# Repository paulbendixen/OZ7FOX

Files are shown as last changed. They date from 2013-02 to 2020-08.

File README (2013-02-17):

This is a project to make an open source / open hardware foxhunt transmitter

All code in this project is released under Beerware license, you may use it 
any way you want. If you like it we would appreciate if you bougth us a beer 
should we meet.

The project is designed to run on an ATMega16 or ATMega32, the hardware should
be available shortly.

Best regards and 73

	Paul M. Bendixen,	OZ6PMB
	Morten E. Bruhn,	OZ1MB

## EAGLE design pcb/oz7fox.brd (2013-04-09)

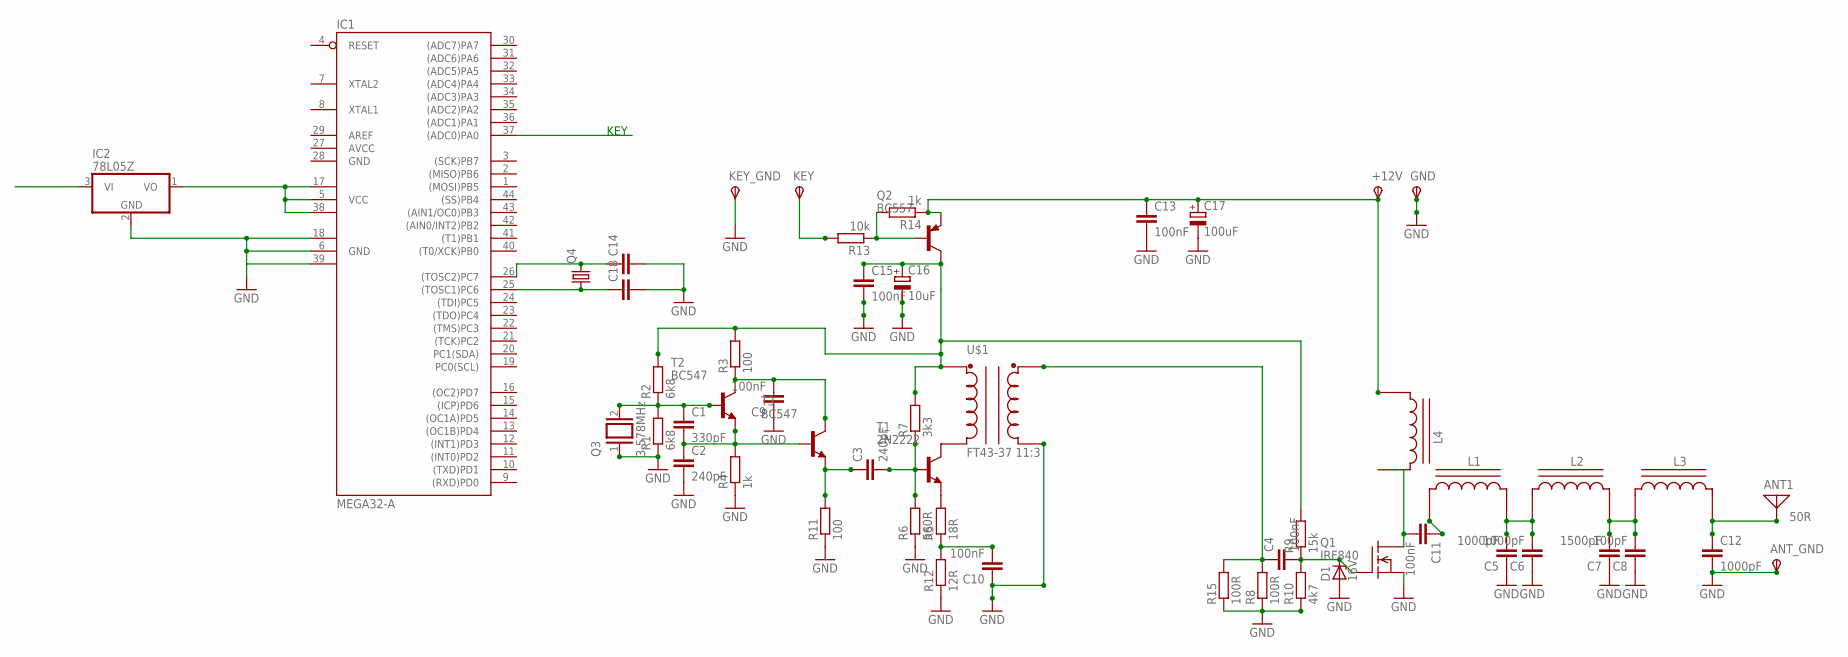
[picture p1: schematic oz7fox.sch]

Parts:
+12V: TPSPAD1-20; P1-20
ANT1: 50R; PAD-01
ANT_GND: TPSPAD1-20; P1-20
C1: 330pF; C150-054X183
C2, C3: 240pF; C150-054X183
C4, C11: 100nF; C150-054X183
C5, C6, C12: 1000pF; C150-054X183
C7: 1500pF; C150-054X183
C8: 100pF; C150-054X183
C9, C10, C13, C15: 100nF; C050-025X075
C14, C18: C5/2.5; C5B2.5
C16: 10uF; E5-13
C17: 100uF; E5-13
D1: 16V; ZDIO12.5
GND: TPSPAD1-20; P1-20
IC1: MEGA32-A; TQFP44
IC2: 78L05Z; TO92
KEY: TPSPAD1-20; P1-20
KEY_GND: TPSPAD1-20; P1-20
L1, L2, L3: T37_INDUCTOR
L4: T37-2 16t; T37_INDUCTOR
Q1: IRF840; TO220
Q2: BC557; TO92
Q3: 3,578MHz; Q
Q4: CRYSTALTC26V; TC26V
R1: 6k8; 0207/12
R2: 6k8; 0207/10
R3, R11: 100; 0207/12
R4, R14: 1k; 0207/12
R5: 18R; 0207/12
R6: 560R; 0207/12
R7: 3k3; 0207/12
R8, R15: 100R; 0207/12
R9: 15k; 0207/12
R10: 4k7; 0207/12
R12: 12R; 0207/12
R13: 10k; 0207/12
T1: 2N2222; TO18
T2, T3: BC547; TO92
U$1: FT43-37 11:3; T37_TRANSFORMER

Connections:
12V: +12V.TP, C13.1, C17.+, IC2.3 (VI), L4.CB, Q2.1 (E), R14.1
AVCC: IC1.27 (AVCC)
GND: ANT_GND.TP, C2.2, C5.1, C6.1, C7.1, C8.1, C9.1, C10.1, C12.2, C13.2, C14.2, C15.2, C16.-, C17.-, C18.2, D1.A, GND.TP, IC1.6 (GND), IC1.18 (GND1), IC1.28 (GND), IC1.39 (GND2), IC2.2 (GND), KEY_GND.TP, Q1.3 (S), Q3.1, R1.1, R4.1, R6.1, R8.1, R10.1, R11.1, R12.1, R15.1, U$1.C2A
KEY: IC1.37 ((ADC0)PA0), KEY.TP, R13.2
unnamed: C1.2, C2.1, R4.2, T2.1 (E), T3.2 (B)
unnamed: C11.1, L1.CB
unnamed: C1.1, Q3.2, R1.2, R2.1, T2.2 (B)
unnamed: C9.2, R3.1, T2.3 (C), T3.3 (C)
unnamed: C15.1, C16.+, Q2.3 (C), R2.2, R3.2, R7.2, R9.2, U$1.C1B
unnamed: C3.1, R11.2, T3.1 (E)
unnamed: C11.2, L4.CA, Q1.2 (D)
unnamed: C3.2, R6.2, R7.1, T1.2 (B)
unnamed: R5.2, T1.1 (E)
unnamed: C10.2, R5.1, R12.2
unnamed: T1.3 (C), U$1.C1A
unnamed: C5.2, C6.2, L1.CA, L2.CB
unnamed: IC1.5 (VCC), IC1.17 (VCC1), IC1.38 (VCC2), IC2.1 (VO)
unnamed: C7.2, C8.2, L2.CA, L3.CB
unnamed: C18.1, IC1.25 ((TOSC1)PC6), Q4.1
unnamed: ANT1.1, C12.1, L3.CA
unnamed: C4.1, R8.2, R15.2, U$1.C2B
unnamed: C4.2, D1.C, Q1.1 (G), R9.1, R10.2
unnamed: C14.1, IC1.26 ((TOSC2)PC7), Q4.2
unnamed: Q2.2 (B), R13.1, R14.2

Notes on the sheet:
KEY

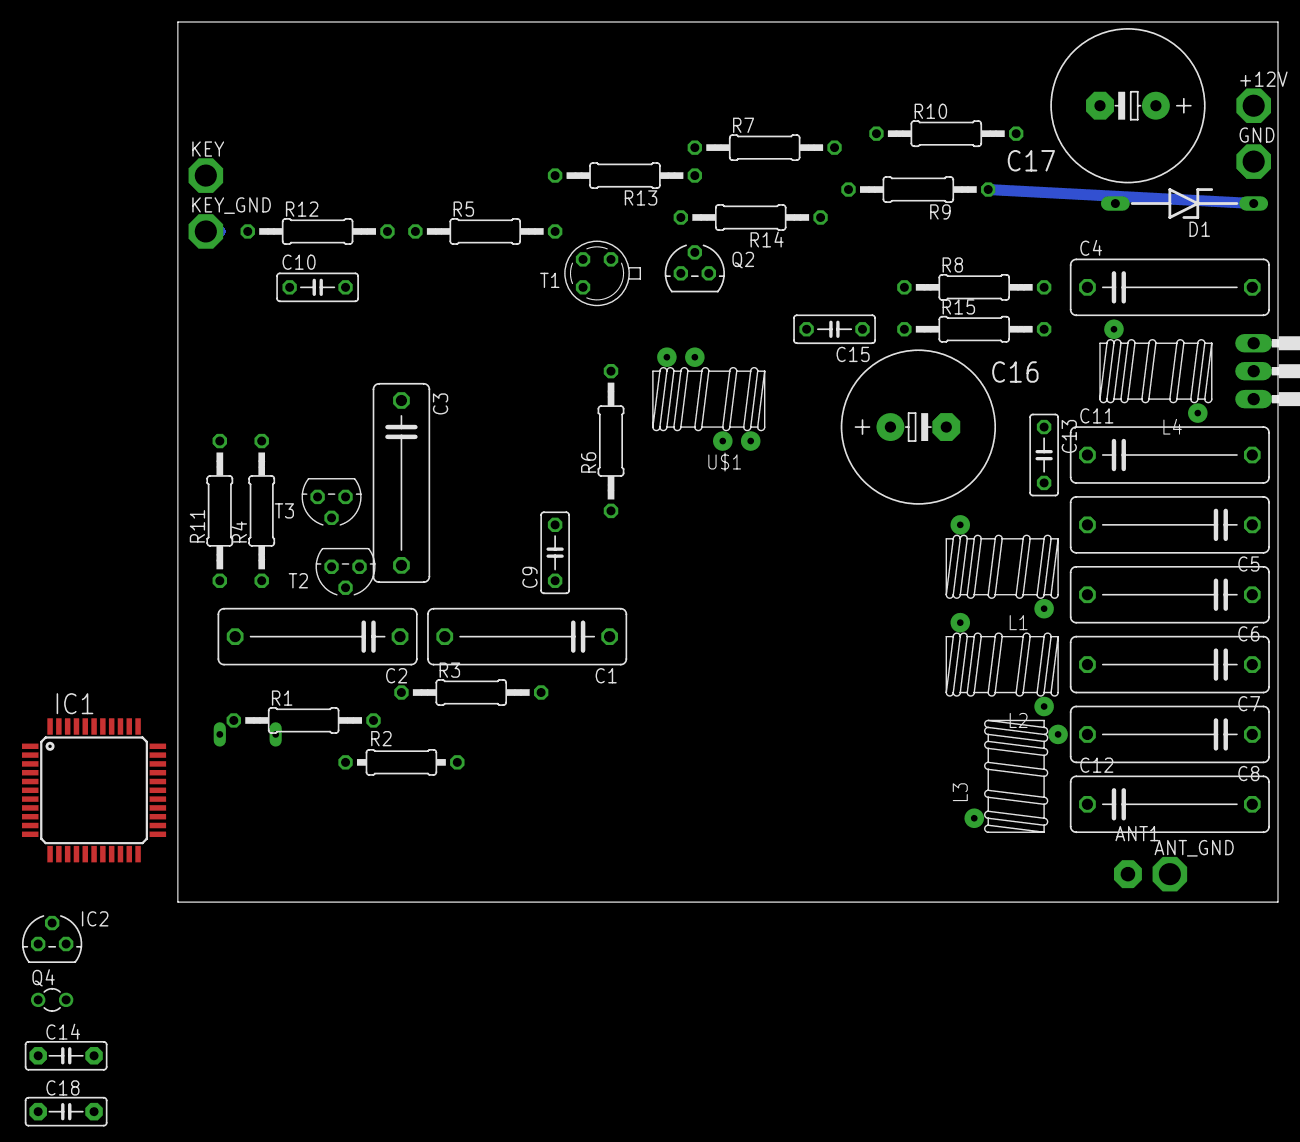
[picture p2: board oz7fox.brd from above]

Board: 2 copper layers, 100.0 x 80.0 mm, 54 parts (1 on the bottom side), 23 nets.

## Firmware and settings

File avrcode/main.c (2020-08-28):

/**
 * @file main.c
 * @brief Main function.
 * @return status code (never returns)
 *
 * The main function does all the fun stuff.
 */

#include <avr/io.h>
#include <avr/sleep.h>
#include "globals.h"
#include "timer.h"
#include "key.h"
#include "main.h"

int main(void)
{
	/// The number of this fox.
	uint8_t thisFoxNo;
	/// The total number of foxes.
	uint8_t totalFoxNo;
	/// Counter variable for fox iteration.
	uint8_t currentFox;
	/// Time spent transmitting fox id (callsign and number)
	ticks_t timeSpent;
	/*
	 * do init stuff
	 */
	initPorts();

	/*
	 * TODO: Make these parameters be selectable from dip switches
	 * or a similar device instead of being statically defined.
	 * thisFoxNo = SELECTOR & 0x0F;
	 * totalFoxNo = (SELECTOR & 0xF0)>>4;
	 */
	thisFoxNo = SELECTOR & 0x0F;
	totalFoxNo = 5;
	
	MORSEPORT = thisFoxNo << 4 | 0x0E;
	// counter/timer register setup
	timerInit(MORSE_COUNTER_COMPARE_VALUE,SLOW_TIMER_COUNT);

	// Enable interrupts.
	sei();

	/* Main loop */
	while (1)
	{
		/* Procedure:
		 * 1. check what fox we are
		 * 2. wait for our time to send
		 * 3. send
		 * 	3a.	send call
		 * 	3b.	send tone
		 * 	3c.	send call
		 * 4. setup sleep time for wakeing up
		 * 5. loop sleep untill we are supposed to wake up
		 */

		enaSlowTimer();
		/* Count through the foxes, wait for it to be our turn. */
		for (currentFox = 0; currentFox < thisFoxNo; currentFox++)
		{
			//sleep for a minute
			deepSleep();
#ifndef NDEBUG
			MORSEPORT ^= 0x80;
#endif
		}
		// Disable the slow timer (for sleeping) and enable the fast timer (for keying)
		disSlowTimer();
		enaFastTimer();

		// Send this fox' ID (including callsign) and record the time spend doing this.
		timeSpent = sendFoxID(thisFoxNo);
		wordSpace(TICKS_INTRA_WORD);

		// Send two consecutitve long beeps followed by short spaces.
		sendLongBeep(HALF_MINUTE - 4 * TICKS_INTER_WORD - timeSpent);
		wordSpace(0);
		sendLongBeep(HALF_MINUTE - 4 * TICKS_INTER_WORD - timeSpent);
		wordSpace(0);

		// retransmit the fox id.
		sendFoxID(thisFoxNo);

		// Disable the fast timer (for keying) and enable the slow timer (for sleeping) 		
		disFastTimer();
		enaSlowTimer();

		currentFox++; // count ourselves
		synchronizeTick();
		for (; currentFox < totalFoxNo; currentFox++)
		{
#ifndef NDEBUG
			MORSEPORT ^=(0x10<<currentFox);;
#endif
			// do the sleep thing again
			deepSleep();
		}
	}
}

/**
 * @brief Transmit the complete ID for this fox, including callsign.
 * @param fox_id	The ID of the fox
 * @return	The number of morse tics spent transmitting the fox ID
 *
 * It consists of its callsign followed by
 * its number. Relevant spacing is automatically added.
 * The number of tics spent doing this is returned afterwards.
 * 
 * Specification of fox ids used in OZ-land (DK) can be found at
 * The EDR foxhunt page:
 * 
 * http://qsl.net/oz7fox/Reglement.htm
 */
ticks_t sendFoxID(uint8_t foxNumber) 
{
	ticks_t totalLength;
	morse_char_t charToSend;
	totalLength = sendCallsign();
	totalLength += wordSpace(TICKS_INTRA_WORD);
#ifdef INTERNATIONAL_FOX_ID
	// All international identifiers are prefixed with 'MO'.
	totalLength += sendChar(mike);
	totalLength += sendChar(oscar);
	switch(foxNumber)
	{
		case 0:	charToSend = echo; break;
		case 1:	charToSend = india; break;
		case 2:	charToSend = sierra; break;
		case 3:	charToSend = hotel; break;
		case 4:	charToSend = five; break;
#else /* INTERNATIONAL_FOX_ID */
/* If international ID is not used, assume OZ identifiers */
	switch(foxNumber)
	{
		case 0:	charToSend = alpha; break;
		case 1:	charToSend = uniform; break;
		case 2:	charToSend = victor; break;
		/* EDR says H, the logical choice based on pattern is 4
		 * TODO: What makes more sense? */
		//case 3:	charToSend = hotel; break; 
		case 3:	charToSend = four; break; 
		case 4:	charToSend = five; break;
		case 5:	charToSend = november; break;
		case 6:	charToSend = delta; break;
		case 7:	charToSend = bravo; break;
#endif /* INTERNATIONAL_FOX_ID */
		default:
			/* We don't know how to name a fox that does
			 * not fit with our predefined patterns,
			 * so we don't. We just broadcast the
			 * callsign and exit. */
			return totalLength;
	}
	return totalLength + sendChar(charToSend);
}

/**
 * @brief Transmit "OZ7FOX" as morse code
 * @return The number of morse tics spent transmitting
 * 
 * OZ7FOX is the call for all foxes in OZ-land (DK).
 */
ticks_t sendCallsign() 
{
	ticks_t count = 0;
	count += sendChar(oscar);
	count += sendChar(zulu);
	count += sendChar(*allChars[7]);
	count += sendChar(foxtrot);
	count += sendChar(oscar);
	count += sendChar(xray);
	return count;
}

/**
 * @brief Initialize the ports on the microprocessor as either input or output ports.
 */
void initPorts() 
{
	// All selector ports are in input mode
	SELECTORSETUP = 0x00;
	SELECTORPULLUP = 0x0F;
	// All morse ports are output ports
	MORSESETUP = 0xFF;
#ifndef NDEBUG
	// D7 toggles every time 6 second timer triggers. Make D7 output.
	DDRD = 1 << 7;
#endif
}

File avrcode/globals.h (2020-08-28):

/**
 * @file	globals.h
 * @brief	Assorted definitions we might use
 */
#ifndef GLOBALS_H
#define GLOBALS_H
#include <avr/io.h>

#ifndef F_CPU
#define F_CPU 1000000UL
//#define F_CPU 3696400
#endif

#define MORSEPORT PORTA
#define MORSESETUP DDRA
#define MORSEPIN 0x01

#define SELECTOR PINB
#define SELECTORPULLUP PORTB
#define SELECTORSETUP DDRB
#define FOXA 0x01
#define FOXU 0x02
#define FOXV 0x04

#define MORSE_UNIT_IN_MILLIS 60

/**
@brief Converts the given time in ms to a clock tick defined by the CPU frq

This timer calculates what count should go into the compare register for the 
fast counter.

The timer is calculated as:

   Timer count = t_milis / prescaler * (F_CPU / 1000) - 1

@warning	The macro MUST NOT exceed the maximum number of
   timer counts which is 2^16 counts.

For a processor clocked at 1MHz, the maximum time roughly
corresponds to 65 milliseconds. 
   
See ATMega16 datasheet p. 100
*/

#define MORSE_COUNTER_COMPARE_VALUE ((MORSE_UNIT_IN_MILLIS * (F_CPU / 1000UL)) - 1)
#if MORSE_COUNTER_COMPARE_VALUE > 0xFFFF
#error MORSE_COUNTER_COMPARE_VALUE too large (>65536). Do something (RTAVRM)
#endif


/* The Interrupt is fired twice a f_{OC2} cycle, since it is the one
 * that toggles the output so t_{OC2} should be 12s.
 * 	      F_{clkIO}
 * f_{OCn} = --------------
 *            2*N*(1+OCRn)
 * 
 *            2*N*(1+OCRn)     2*1024*(1+192)
 * t_OCn =  --------------- = -------------- = 12
 *             F_clkIO          32.768
 */
#define SLOW_TIMER_COUNT 191
#define SPACE_LENGTH 7
#define HALF_MINUTE (30000 / MORSE_UNIT_IN_MILLIS)

extern uint8_t minuteCounter;

#endif // GLOBALS_H

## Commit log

2012-11-27 Compiles and burns using the new Makefile, but does not work yet
    [globals.h, main.c]
2012-12-11 Leds actually blink now
    The leds now actually blink.
    The problem was the way the registers were set as well as the need for
    the correct registers to be set.
    [main.c]
2012-12-11 Made the morse coder morse code - do not connect to radio
    Added code to send morse code, consider making it more user friendly.
    Changed the Makefile to use the correct programmer (stk500v2) so that
    programming is done faster.
    The test program now sends out SOS two times with letter and word
    spacing between.
    NEVER SEND OUT SOS FOR TESTING!!!
    [main.c]
2012-12-12 Changed the period of the morse (40wpm)
    Changed the period to use 40 wpm instead of arbitrary.
    Used on the notion that paris is 43 chars long.
    Made the opportunity for setting in the fox at the correct point in the
    sequence.
    [main.c]
2013-01-08 Something doesn't work, but I'm tired
    [globals.h, main.c]
2013-02-14 Wakeup timer works, timing is wrong thoug
    Also changed the morse code to send out OZ7FOX instead of SOS.
    Some debug LEDs still remain in this version.
    [main.c]
2013-02-16 Fixed the timing problems
    Also made the timing variables a bit more opaque and added some comments
    and references to the datasheet
    [globals.h, main.c]
2013-02-16 Moved timing related functions to timer.c/h
    Fixed the timing problem, it is now synchronized
    The project is now functional, the rest should just be pretty printing
    [main.c]
2013-02-16 Rewrote handling of timer counts.
    Timer count is now calculated by a macro in globals.h
    The timer count MUST NOT exceed 2^16. This is NOT checked at
    compile time, so use of the macro should be done with caution.
2013-02-16 Added doxygen comments and fixed minor bugs.
    Elaborated on doxygen-related comments, primarily in main.c.
    Fixed minor bug in key.c.
    [main.c]
2013-02-17 Moved the doxygen comment in main.c so it gets in
    Also corrected the atrocious space indenting Boris had done
    [main.c]
2013-02-18 Refactored timing of morse, wrote comments
    all: All functions that measure time in morse ticks now use the
    type ticks_t to reflect that we deal in morse ticks
    rather than clock cycles or milliseconds.
    key.h:
    - The macro assignments that turn the morse pin on and off
    now have their own macros MORSE_ON and MORSE_OFF.
    - All spacings in morse now have their own macros defining
    spaces in terms of morse ticks.
    - Reversed order of arguments to macro EXTRACT_MORSE_BIT to reflect
    the order of the pattern and length in morse_char_t.
    key.c:
    - The sendChar() should now handle spacing between characters
    correctly without help.
    - We now have charSpace(), wordSpace() and space() to deal with
    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
    [main.c]
2013-02-18 Fixed indentation
    I have now fixed my VIM so that it handles indentations
    by using the TAB character, like its creator paulbendixen
    has specified. Conflicts with my spaces-based indentation
    is visible once tabspace is interpreted differently :(
    [main.c]
2013-03-17 Changed platform and added string sending
    First change is that the target is now the MEGA32 controller.
    This is the one on the AVR stamp that Bertho has made available at
    http://www.vagrearg.org/content/avrpicstamp
    The second change is that by doing an arary of morse components
    it is now possible to send an actual string.
    I'm beginning to think we might need some kind of unit testing,
    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
2013-04-09 Moved the code to subfolder and added a pcb dir
    All code is move to the avrcode subdirectory
    The PCB is added to the pcb subdirectory
    [oz7fox.brd, oz7fox.sch]
